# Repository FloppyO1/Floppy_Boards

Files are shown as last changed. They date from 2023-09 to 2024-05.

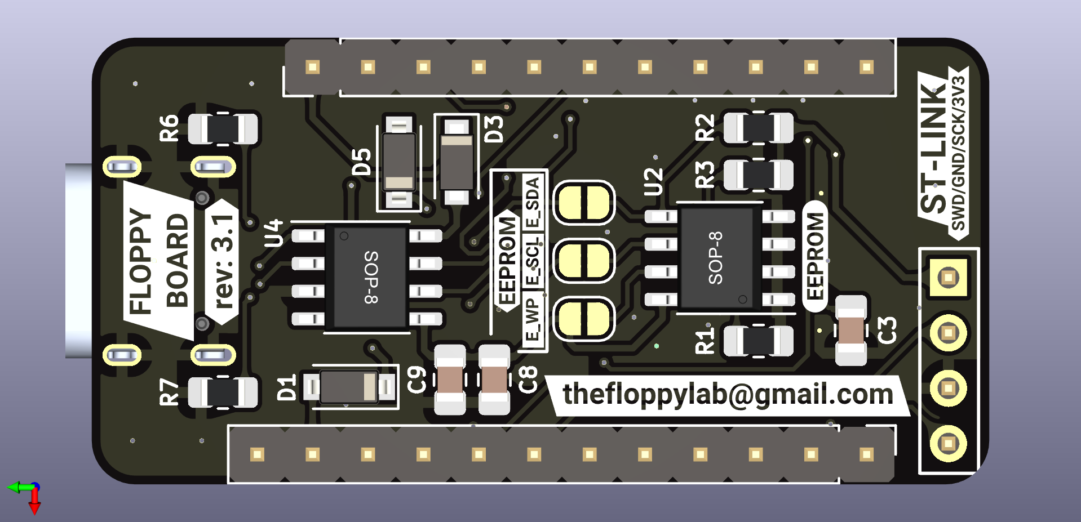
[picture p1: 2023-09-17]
Floppy Board/Floppy Board 3/Floppy Board v3.1/IMAGES/Floppy Board v3.1 bottom.png

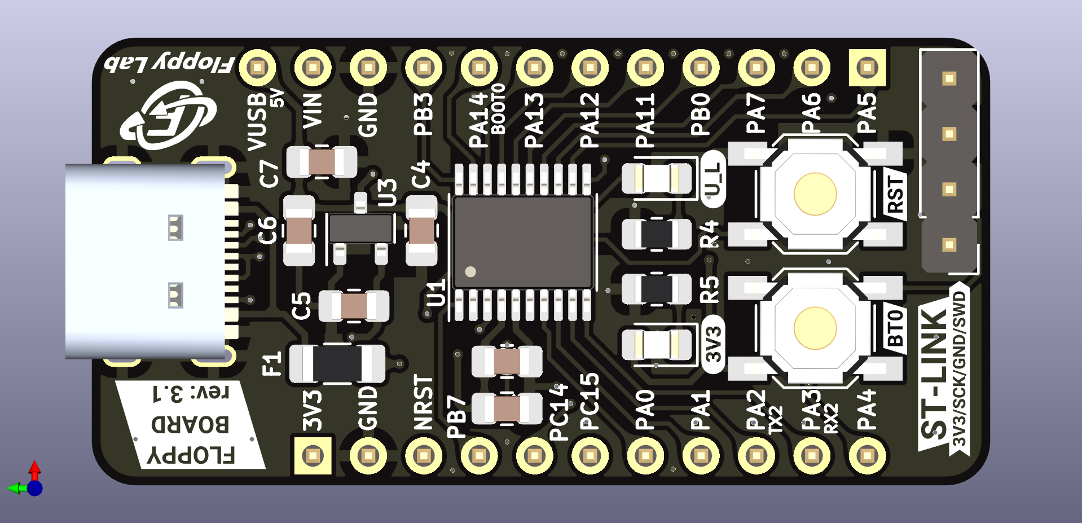
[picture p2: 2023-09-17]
Floppy Board/Floppy Board 3/Floppy Board v3.1/IMAGES/Floppy Board v3.1 top.png

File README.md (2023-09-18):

# Floppy_Boards
Floppy Boards are a series of breakout boards for rapid prototyping which I developed as an alternative of Arduino.

These boards can provide good performance and many useful modules (such as: USB, I2C, SPI, timers etc.). I want to make several models, in order to have different boards for different applications.
For example, I am considering developing options for:

- Built-in battery monitoring & charging.   (to be done)
- Built-in DC motor control.                (to be done)
- Built-in servos & stepper-motor control.  (to be done)

# Why as an alternative to Arduino boards?
I am building this board because I was looking for a cheap, powerful and well supported development board in the marketplace, but I don’t find anything I like. On the other hand, I am learning a lot while making these Floppy Boards.
## Features
- Programmable with Arduino IDE and STMCubeIDE
- Planty of the module
- Small dimensions
- Lots of GPIO

### The most recent version I've made
Floppy Bard 3.1

The third version of the Floppy Board, this board has incorporated all possible improvements regarding the interface between the Floppy Board and the computer.
In this version, it excels over the others in the following aspects:

- The last upgrade includes a USB-C port, allowing you to power our projects and load firmware directly without the need for an ST-Link.
- Additionally, the board has been further downsized, featuring two holes on each side when inserted into a breadboard!
- I've added a pin where you can access the incoming 5V voltage from the USB , enabling you to power external circuits directly from the convenient USB-C.
- The silkscreen has been completely updated, making it much more legible and aesthetically pleasing.
- inally, we've introduced the option to install an EEPROM on the back of the board , enabling you to permanently save small amounts of data even in the absence of power.

## Other informations

For more informations check my website: https://floppylab.altervista.org/en

You can also find some information on my YouTube channel: https://www.youtube.com/@floppylab

## Support this project with a donation

To support this project you can make a donation via PayPal or buy a Floppy Board:

https://www.paypal.com/paypalme/floppylab

https://ko-fi.com/floppylab



## License

[CERN Open Hardware Licence Version 2 - Strongly Reciprocal](https://choosealicense.com/licenses/cern-ohl-s-2.0/#)

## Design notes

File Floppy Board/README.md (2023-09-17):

# Floppy Board

Inside this folder there are all the files of the base version of the Floppy Board.

There are 3 major versions:
- v1.0, that is the first prototype that I've made.
- v2.0, which is the second attempt, is an improved version of 1.0, it is good because it is the smallest of the three versions.
- v3.x, which is the last version that includes the connections between the Floppy Board and the computer.



## License

[CERN Open Hardware Licence Version 2 - Strongly Reciprocal](https://choosealicense.com/licenses/cern-ohl-s-2.0/#)

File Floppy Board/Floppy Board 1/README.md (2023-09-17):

# Floppy Board rev:1.0

[](https://floppylab.altervista.org/wp-content/uploads/2023/09/FB-1-no-sfondo-960x768.png)

This is the first prototype of the Floppy Board.



## License

[CERN Open Hardware Licence Version 2 - Strongly Reciprocal](https://choosealicense.com/licenses/cern-ohl-s-2.0/#)

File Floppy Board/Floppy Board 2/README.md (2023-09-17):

# Floppy Board rev:2.0


This is the second version of the Floppy Board, and it includes a few small improvements that make it simpler and faster to use.
The improvements that I made are as follows:

- The total width has been reduced, allowing this version to be used with only one breadboard.
- The 3.3V output pin now has precisely 3.3V (3.263V), ensuring no more 3V output!
- Pin names have been added on each side of the board.
- The board now has a slimmer profile that makes it possible to use it upside down.
- The microcontroller is the same as the first Floppy Board, but it can be upgraded with an equivalent MCU that has double the FLASH memory. The more capable MCU is the STM32G031F8P6, which has 32kB more memory than the old one (so 64kB in total). These boards are compatible with Arduino IDE, meaning they can be easily programmed by users who are less experienced.



## License

[CERN Open Hardware Licence Version 2 - Strongly Reciprocal](https://choosealicense.com/licenses/cern-ohl-s-2.0/#)

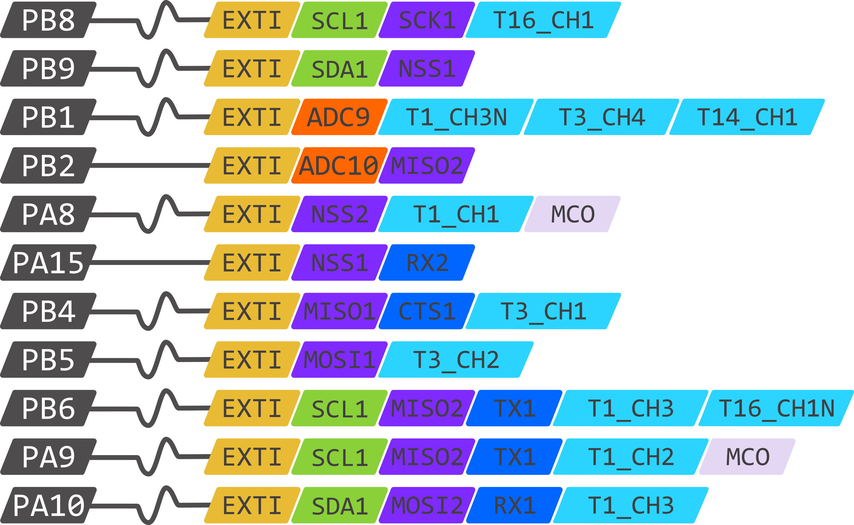
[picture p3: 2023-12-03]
pinouts/originals/fb3.1/pinout FB3 2.png

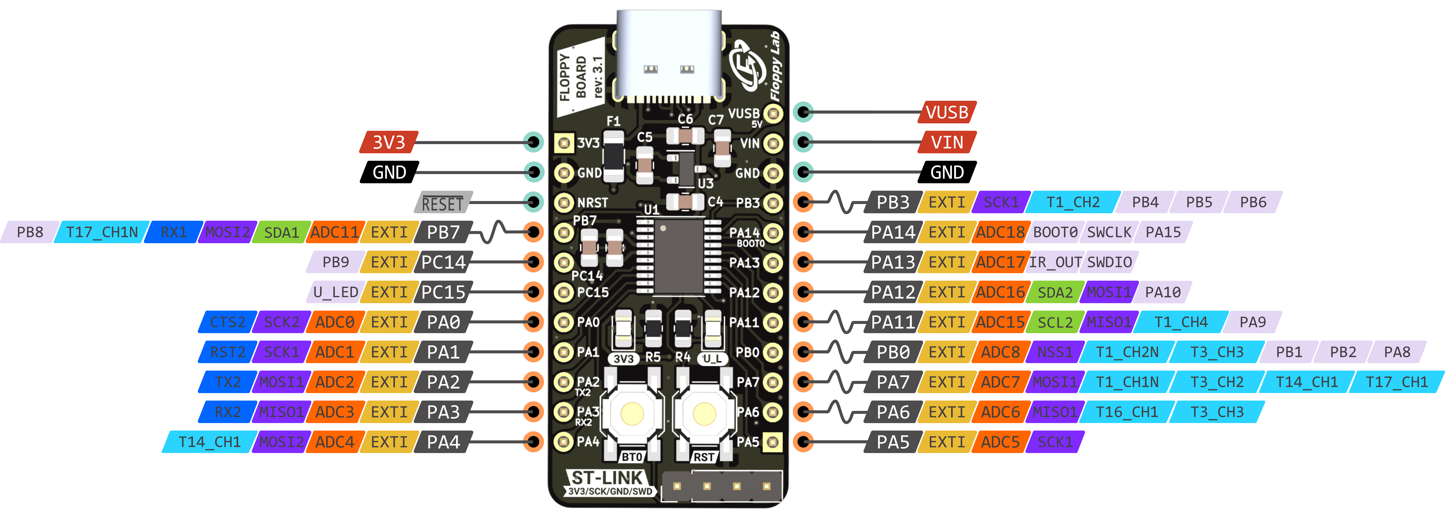
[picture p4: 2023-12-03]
pinouts/originals/fb3.1/pinout FB3 1.png

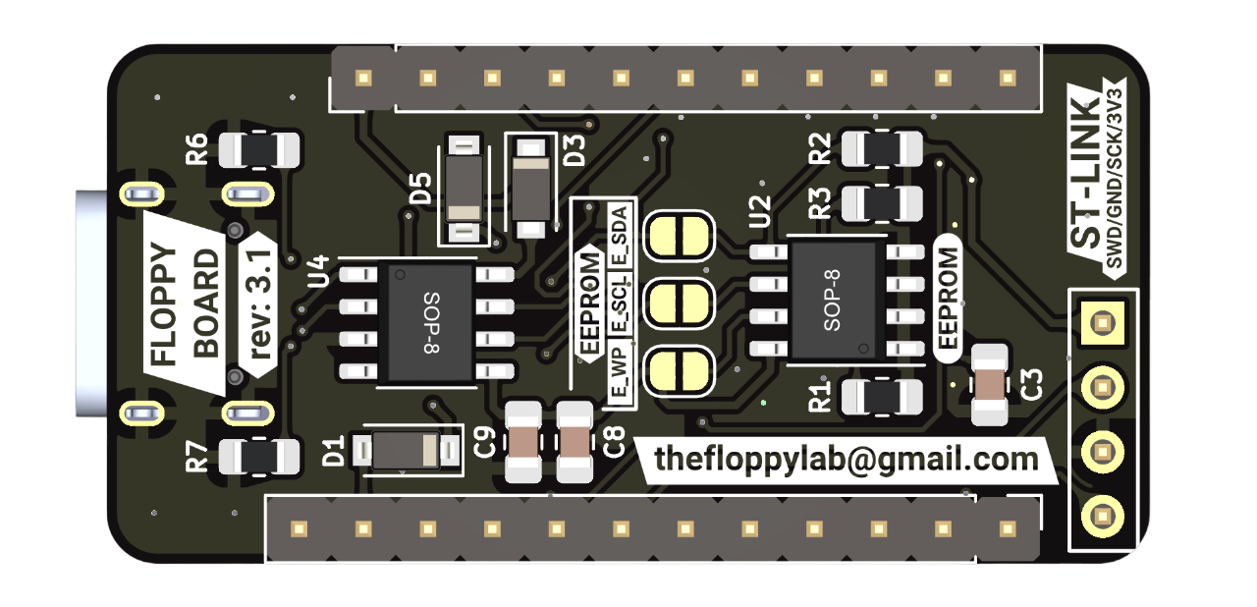
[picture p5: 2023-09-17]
Floppy Board/Floppy Board 3/Floppy Board v3.1/IMAGES/Floppy Board v3.1 bottom senza sfondo.png

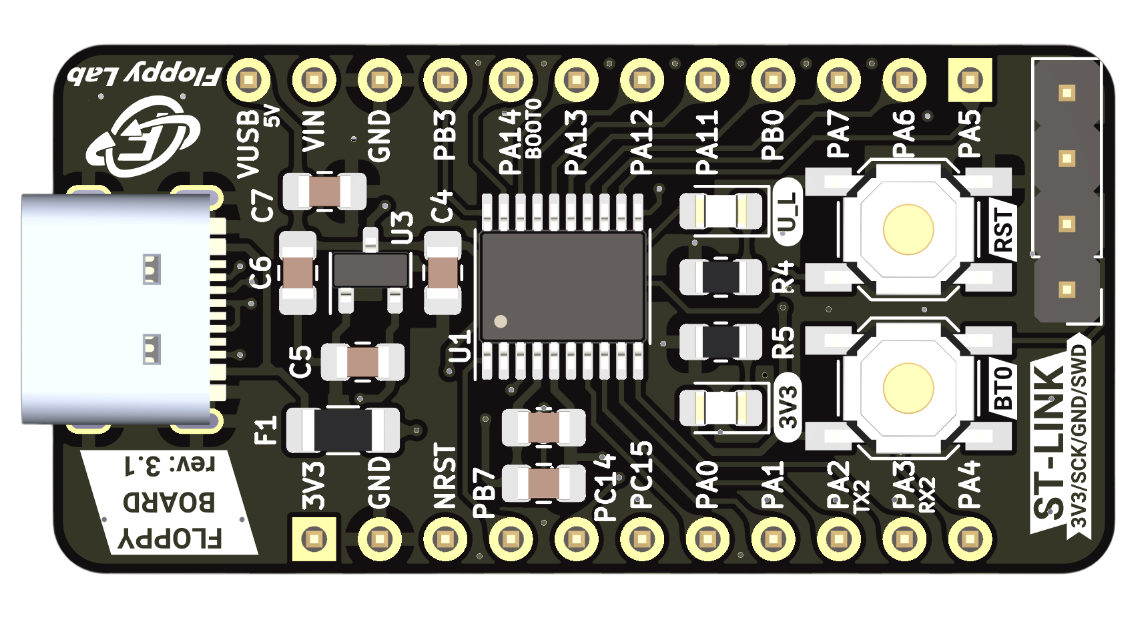
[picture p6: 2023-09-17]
Floppy Board/Floppy Board 3/Floppy Board v3.1/IMAGES/Floppy Board v3.1 top senza sfondo.png

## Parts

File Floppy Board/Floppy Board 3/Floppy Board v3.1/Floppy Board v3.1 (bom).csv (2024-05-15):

Reference | Value | Footprint | Qtà
C1 | 4.7uF | Capacitor_SMD:C_0805_2012Metric_Pad1.18x1.45mm_HandSolder | 1
C2, C3, C6, C8, C9 | 100nF | Capacitor_SMD:C_0805_2012Metric_Pad1.18x1.45mm_HandSolder | 5
C4, C5 | 1uF | Capacitor_SMD:C_0805_2012Metric_Pad1.18x1.45mm_HandSolder | 2
C7 | 10uF | Capacitor_SMD:C_0805_2012Metric_Pad1.18x1.45mm_HandSolder | 1
D1, D5 | SD103AW | Diode_SMD:D_SOD-123 | 2
D2 | USER_LED | LED_SMD:LED_0805_2012Metric_Pad1.15x1.40mm_HandSolder | 1
D3 | SD103AW | Diode_SMD:D_SOD-123F | 1
D4 | 3V3_POWER_LED | LED_SMD:LED_0805_2012Metric_Pad1.15x1.40mm_HandSolder | 1
F1 | 500mA | Fuse:Fuse_1206_3216Metric_Pad1.42x1.75mm_HandSolder | 1
J1 | st-link | Connector_PinHeader_2.54mm:PinHeader_1x04_P2.54mm_Vertical | 1
J2 | USB-C_304A-ACP16X | _MIA footprint:USB_C_304A-ACP16X | 1
J3 | I/O SX | Connector_PinHeader_2.54mm:PinHeader_1x11_P2.54mm_Vertical | 1
J4 | I/0 DX | Connector_PinHeader_2.54mm:PinHeader_1x12_P2.54mm_Vertical | 1
JP1 | SDA_JP | Jumper:SolderJumper-2_P1.3mm_Open_RoundedPad1.0x1.5mm | 1
JP2 | SCL_JP | Jumper:SolderJumper-2_P1.3mm_Open_RoundedPad1.0x1.5mm | 1
JP3 | WP_JP | Jumper:SolderJumper-2_P1.3mm_Open_RoundedPad1.0x1.5mm | 1
R1 | 10k | Resistor_SMD:R_0805_2012Metric_Pad1.20x1.40mm_HandSolder | 1
R2, R3, R6, R7 | 5.1k | Resistor_SMD:R_0805_2012Metric_Pad1.20x1.40mm_HandSolder | 4
R4 | 1K | Resistor_SMD:R_0805_2012Metric_Pad1.20x1.40mm_HandSolder | 1
R5 | 1k | Resistor_SMD:R_0805_2012Metric_Pad1.20x1.40mm_HandSolder | 1
SW1 | RESET_B | _MIA footprint:SMD BUTTON 5.1x5.1 | 1
SW2 | BOOT0/U_BUTT | _MIA footprint:SMD BUTTON 5.1x5.1 | 1
U1 | STM32G03xxxxx | Package_SO:TSSOP-20_4.4x6.5mm_P0.65mm | 1
U2 | AT24C32 | Package_SO:SOP-8_3.9x4.9mm_P1.27mm | 1
U3 | H7233-1 | Package_TO_SOT_SMD:SOT-23 | 1
U4 | CH340N | Package_SO:SOP-8_3.9x4.9mm_P1.27mm | 1

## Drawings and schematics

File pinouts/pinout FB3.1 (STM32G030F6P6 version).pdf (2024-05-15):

## STM32G030F6P6 version

# Floppy Board 3.1 PINOUT

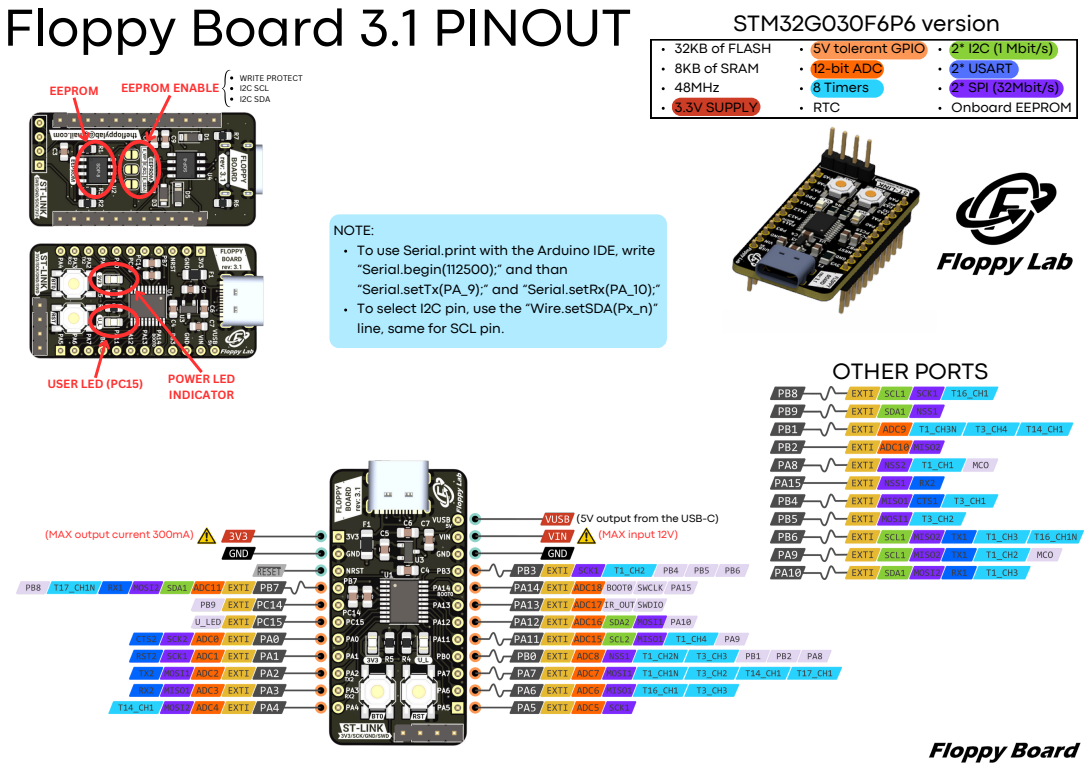
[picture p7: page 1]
3.3V SUPPLY; RTC; Onboard EEPROM; OTHER PORTS; (MAX output current 300mA); (MAX input 12V); EEPROM; EEPROM ENABLE; WRITE PROTECT I2C SCL I2C SDA; POWER LED INDICATOR; USER LED (PC15)

32KB of FLASH 8KB of SRAM 48MHz | 5V tolerant GPIO | | 2* I2C (1 Mbit/s)

12-bit ADC | | 2* USART
8 Timers | | 2* SPI (32Mbit/s)

NOTE:
To use Serial.print with the Arduino IDE, write
“Serial.begin(112500);” and than
“Serial.setTx(PA_9);” and “Serial.setRx(PA_10);”
To select I2C pin, use the “Wire.setSDA(Px_n)”
line, same for SCL pin.

(5V output from the USB-C)

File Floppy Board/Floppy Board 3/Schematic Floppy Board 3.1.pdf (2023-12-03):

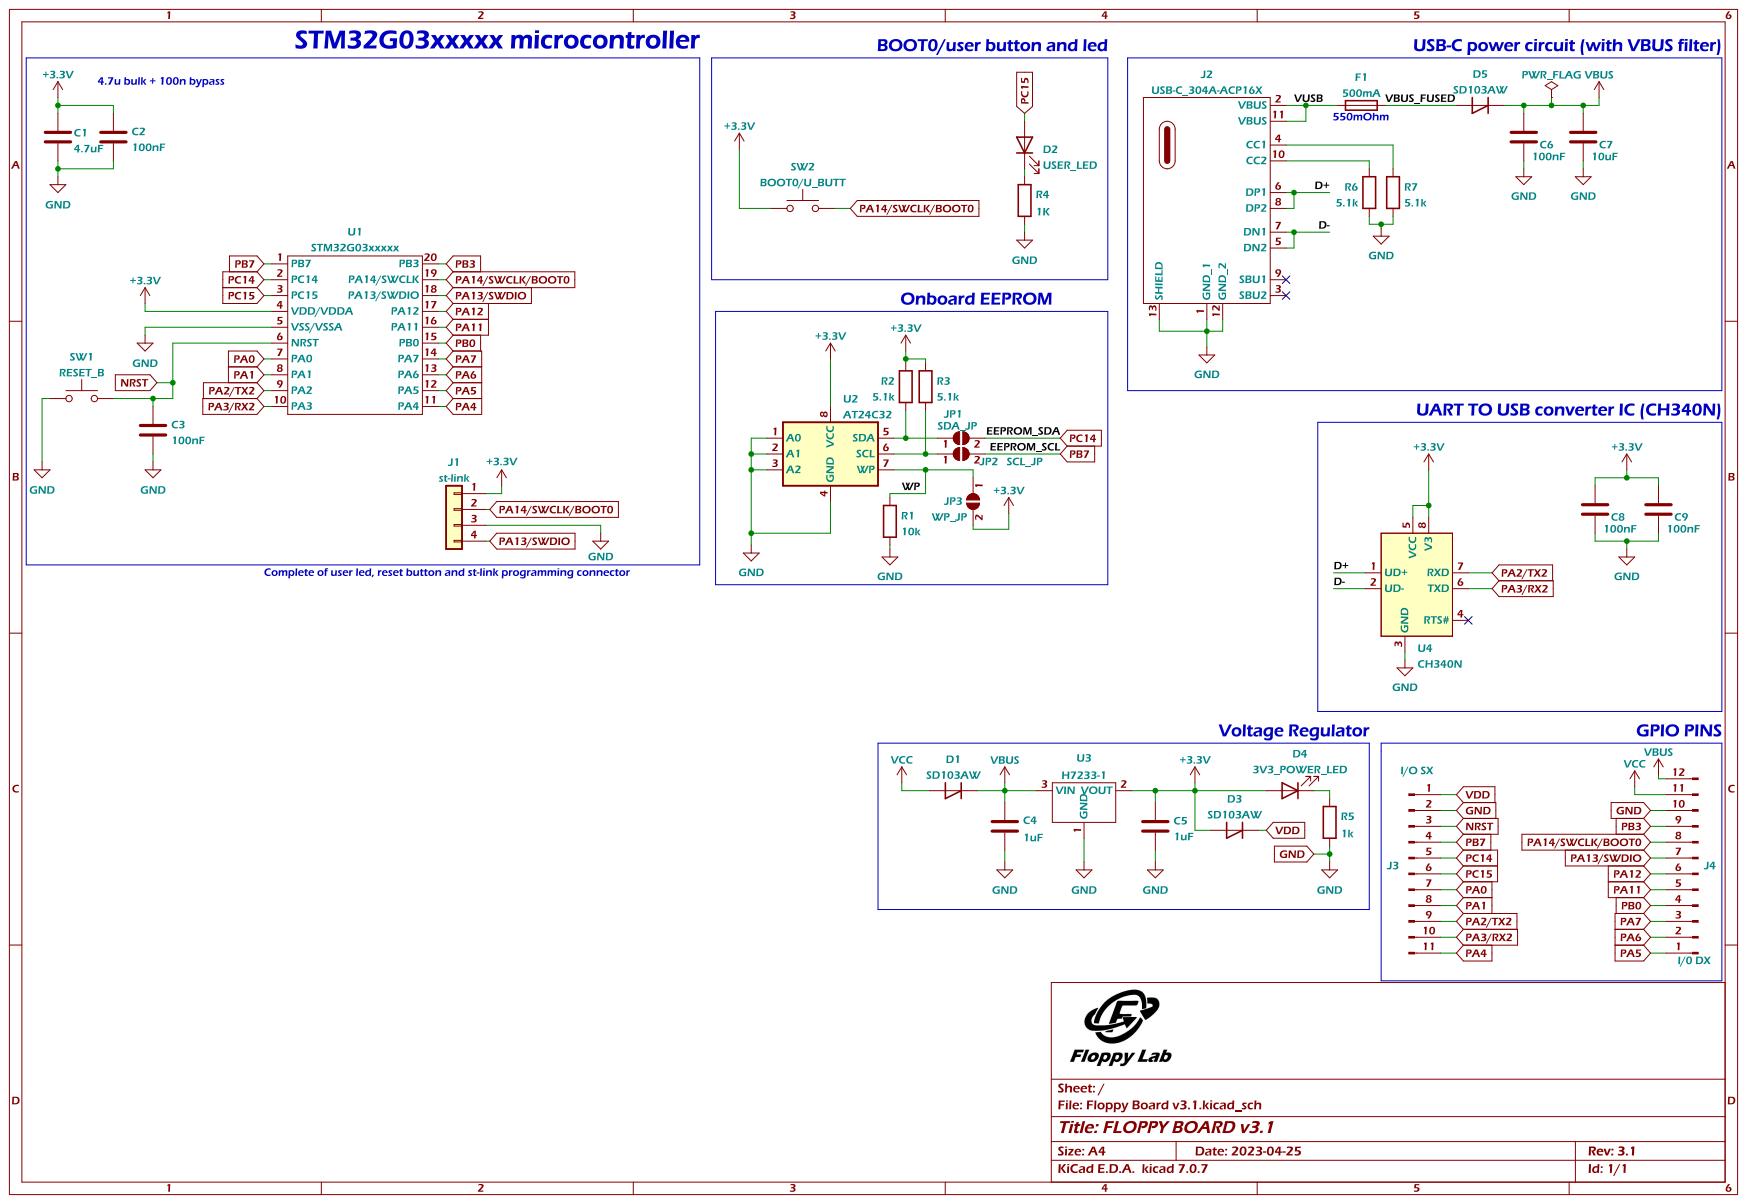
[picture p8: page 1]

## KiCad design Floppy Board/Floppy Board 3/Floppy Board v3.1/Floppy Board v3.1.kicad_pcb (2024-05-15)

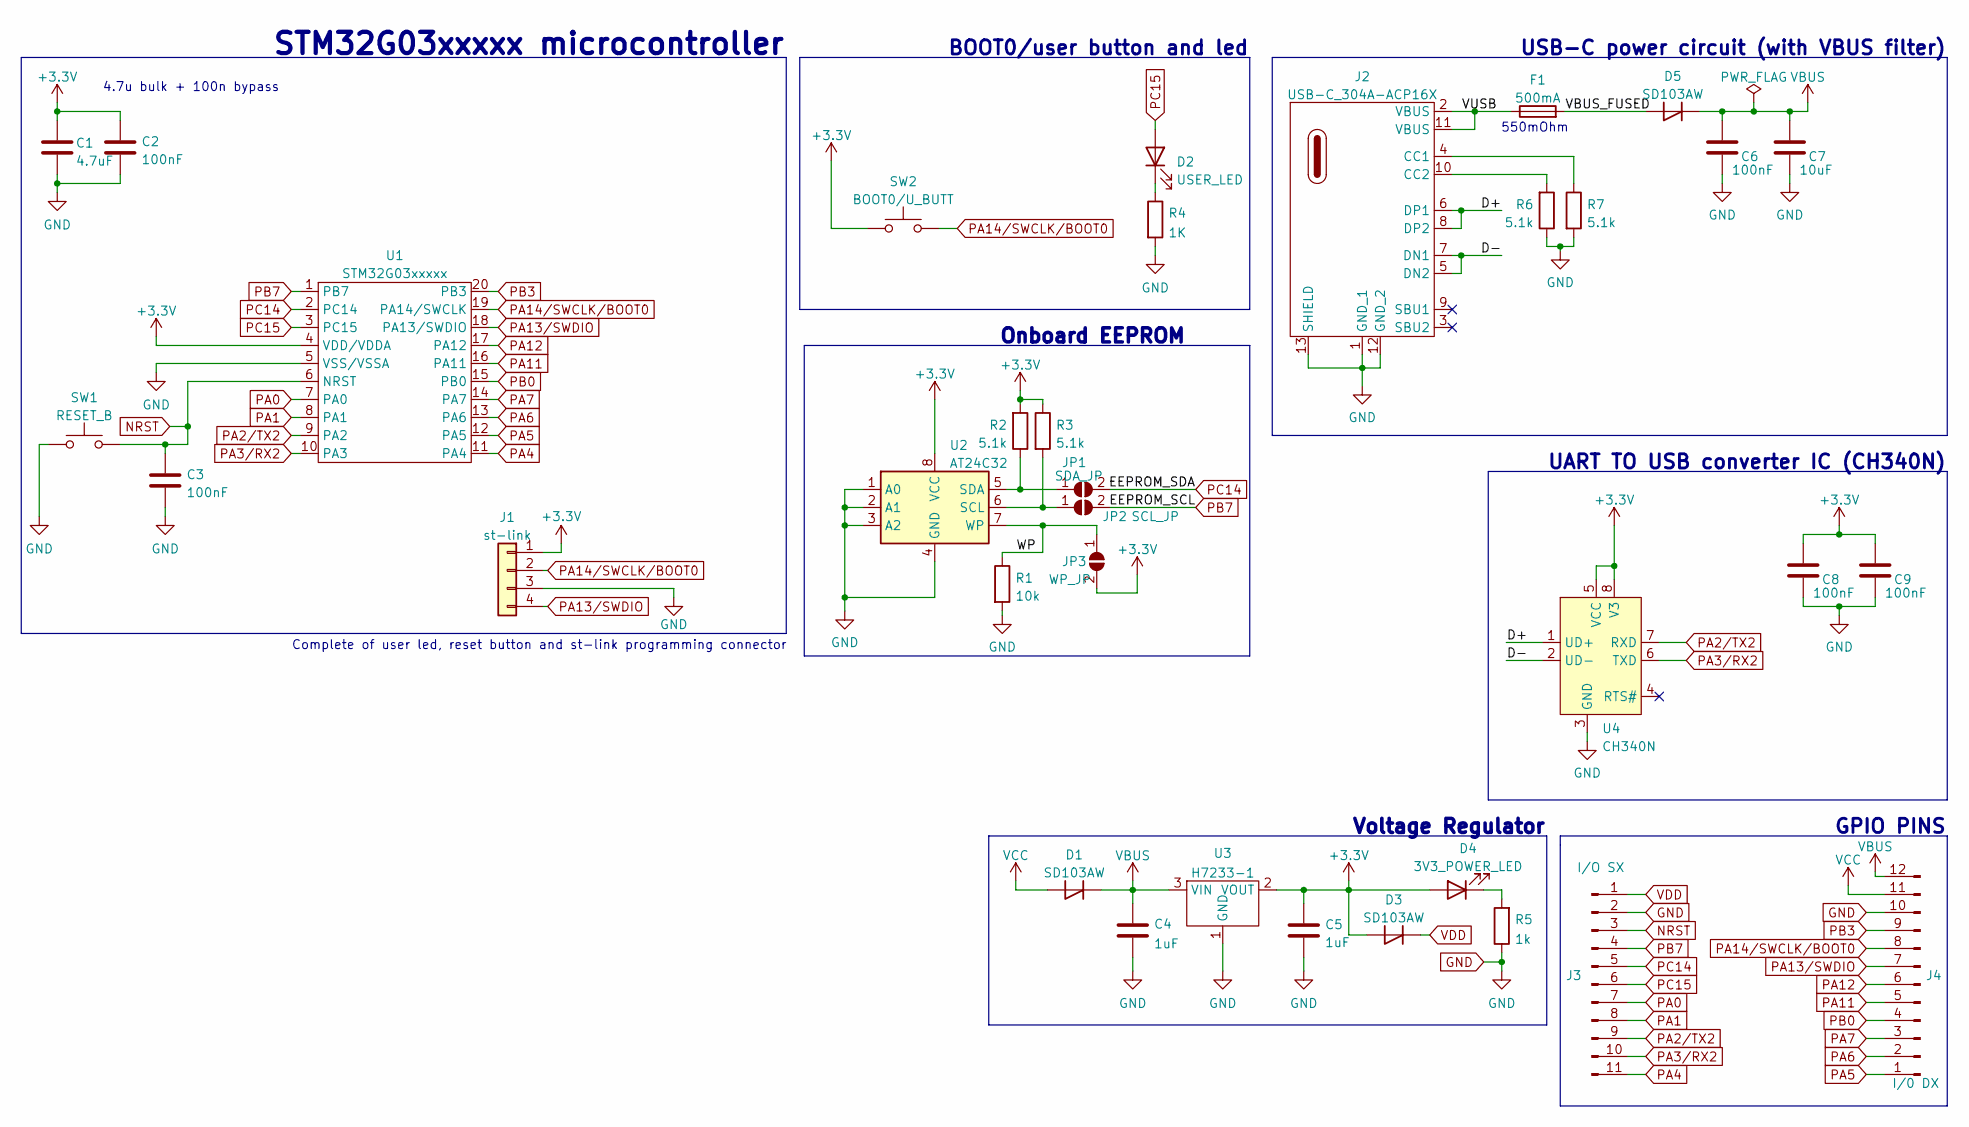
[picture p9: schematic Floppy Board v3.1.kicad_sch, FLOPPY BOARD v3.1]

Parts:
C1: 4.7uF; C_0805_2012Metric_Pad1.18x1.45mm_HandSolder
C2, C3, C6, C8, C9: 100nF; C_0805_2012Metric_Pad1.18x1.45mm_HandSolder
C4, C5: 1uF; C_0805_2012Metric_Pad1.18x1.45mm_HandSolder
C7: 10uF; C_0805_2012Metric_Pad1.18x1.45mm_HandSolder
D1, D5: SD103AW; D_SOD-123
D2: USER_LED; LED_0805_2012Metric_Pad1.15x1.40mm_HandSolder
D3: SD103AW; D_SOD-123F
D4: 3V3_POWER_LED; LED_0805_2012Metric_Pad1.15x1.40mm_HandSolder
F1: 500mA; Fuse_1206_3216Metric_Pad1.42x1.75mm_HandSolder
J1: st-link; PinHeader_1x04_P2.54mm_Vertical
J2: USB-C_304A-ACP16X; USB_C_304A-ACP16X
J3: I/O SX; PinHeader_1x11_P2.54mm_Vertical
J4: I/0 DX; PinHeader_1x12_P2.54mm_Vertical
JP1: SDA_JP; SolderJumper-2_P1.3mm_Open_RoundedPad1.0x1.5mm
JP2: SCL_JP; SolderJumper-2_P1.3mm_Open_RoundedPad1.0x1.5mm
JP3: WP_JP; SolderJumper-2_P1.3mm_Open_RoundedPad1.0x1.5mm
R1: 10k; R_0805_2012Metric_Pad1.20x1.40mm_HandSolder
R2, R3, R6, R7: 5.1k; R_0805_2012Metric_Pad1.20x1.40mm_HandSolder
R4: 1K; R_0805_2012Metric_Pad1.20x1.40mm_HandSolder
R5: 1k; R_0805_2012Metric_Pad1.20x1.40mm_HandSolder
SW1: RESET_B; SMD BUTTON 5.1x5.1
SW2: BOOT0/U_BUTT; SMD BUTTON 5.1x5.1
U1: STM32G03xxxxx; TSSOP-20_4.4x6.5mm_P0.65mm
U2: AT24C32; SOP-8_3.9x4.9mm_P1.27mm
U3: H7233-1; SOT-23
U4: CH340N; SOP-8_3.9x4.9mm_P1.27mm

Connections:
+3V3: C1.1, C2.1, C5.1, C8.1, C9.1, D3.2 (A), D4.2 (A), J1.1, JP3.2 (B), R2.2, R3.1, SW2.1, U1.4 (VDD/VDDA), U2.8 (VCC), U3.2 (VOUT), U4.5 (VCC), U4.8 (V3)
/D+: J2.6 (DP1), J2.8 (DP2), U4.1 (UD+)
/D-: J2.5 (DN2), J2.7 (DN1), U4.2 (UD-)
/VBUS_FUSED: D5.2 (A), F1.2
/VUSB: F1.1, J2.2 (VBUS), J2.11 (VBUS)
/WP: JP3.1 (A), R1.1, U2.7 (WP)
GND: C1.2, C2.2, C3.2, C4.2, C5.2, C6.2, C7.2, C8.2, C9.2, J1.3, J2.1 (GND_1), J2.12 (GND_2), J2.13 (SHIELD), J3.2, J4.10, R1.2, R4.2, R5.1, R6.1, R7.2, SW1.1, U1.5 (VSS/VSSA), U2.1 (A0), U2.2 (A1), U2.3 (A2), U2.4 (GND), U3.1 (GND), U4.3 (GND)
NRST: C3.1, J3.3, SW1.2, U1.6 (NRST)
unnamed: D2.1 (K), R4.1
unnamed: D4.1 (K), R5.2
unnamed: J2.4 (CC1), R7.1
unnamed: J2.10 (CC2), R6.2
unnamed: JP1.1 (A), R2.1, U2.5 (SDA)
unnamed: JP2.1 (A), R3.2, U2.6 (SCL)
PA0: J3.7, U1.7 (PA0)
PA1: J3.8, U1.8 (PA1)
PA2/TX2: J3.9, U1.9 (PA2), U4.7 (RXD)
PA3/RX2: J3.10, U1.10 (PA3), U4.6 (TXD)
PA4: J3.11, U1.11 (PA4)
PA5: J4.1, U1.12 (PA5)
PA6: J4.2, U1.13 (PA6)
PA7: J4.3, U1.14 (PA7)
PA11: J4.5, U1.16 (PA11)
PA12: J4.6, U1.17 (PA12)
PA13/SWDIO: J1.4, J4.7, U1.18 (PA13/SWDIO)
PA14/SWCLK/BOOT0: J1.2, J4.8, SW2.2, U1.19 (PA14/SWCLK)
PB0: J4.4, U1.15 (PB0)
PB3: J4.9, U1.20 (PB3)
PB7: J3.4, JP2.2 (B), U1.1 (PB7)
PC14: J3.5, JP1.2 (B), U1.2 (PC14)
PC15: D2.2 (A), J3.6, U1.3 (PC15)
VBUS: C4.1, C6.1, C7.1, D1.1 (K), D5.1 (K), J4.12, U3.3 (VIN)
VCC: D1.2 (A), J4.11
VDD: D3.1 (K), J3.1

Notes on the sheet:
USB-C power circuit (with VBUS filter)
4.7u bulk + 100n bypass
Voltage Regulator
STM32G03xxxxx microcontroller
550mOhm
GPIO PINS
UART TO USB converter IC (CH340N)
BOOT0/user button and led
Complete of user led, reset button and st-link programming connector
Onboard EEPROM

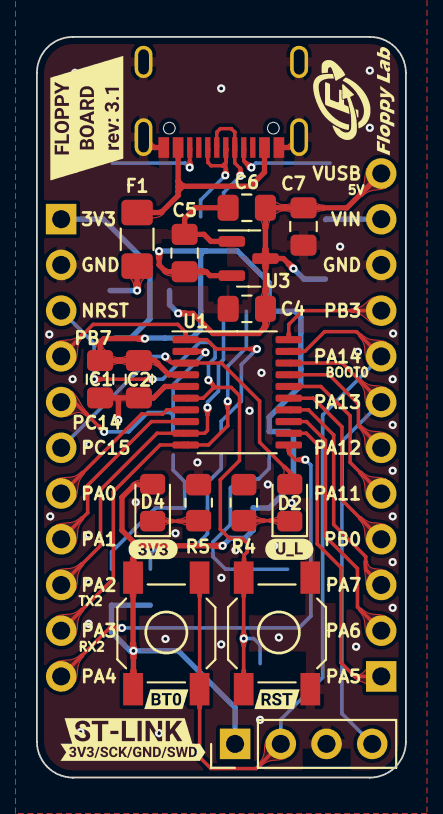
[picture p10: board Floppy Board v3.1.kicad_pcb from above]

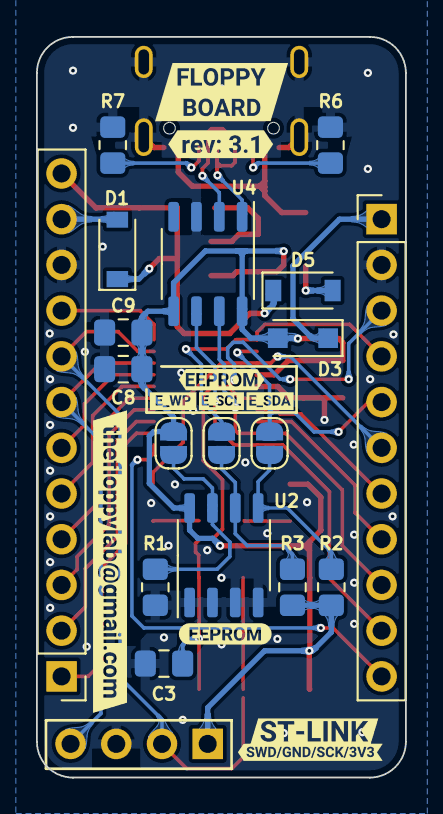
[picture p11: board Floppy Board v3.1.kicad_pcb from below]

Board: 2 copper layers, 20.5 x 41.1 mm, 52 parts (28 on the bottom side), 34 nets.

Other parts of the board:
kibuzzard-644D5A83: G***; kibuzzard-644D5A83
kibuzzard-644D5AD1: G***; kibuzzard-644D5AD1
kibuzzard-644D5AFD: G***; kibuzzard-644D5AFD
kibuzzard-644D5B14: G***; kibuzzard-644D5B14
kibuzzard-644D5C5F: G***; kibuzzard-644D5C5F
kibuzzard-644D5C68: G***; kibuzzard-644D5C68
kibuzzard-644D5C93: G***; kibuzzard-644D5C93
kibuzzard-644D5CBA: G***; kibuzzard-644D5CBA
kibuzzard-644D5F43: G***; kibuzzard-644D5F43
kibuzzard-644D56F9: G***; kibuzzard-644D56F9
kibuzzard-644D58F1: G***; kibuzzard-644D58F1
kibuzzard-644D571B: G***; kibuzzard-644D571B
kibuzzard-644D5750: G***; kibuzzard-644D5750
kibuzzard-644D5758: G***; kibuzzard-644D5758
kibuzzard-644D5814: G***; kibuzzard-644D5814
kibuzzard-644D5953: G***; kibuzzard-644D5953
kibuzzard-644D6722: G***; kibuzzard-644D6722

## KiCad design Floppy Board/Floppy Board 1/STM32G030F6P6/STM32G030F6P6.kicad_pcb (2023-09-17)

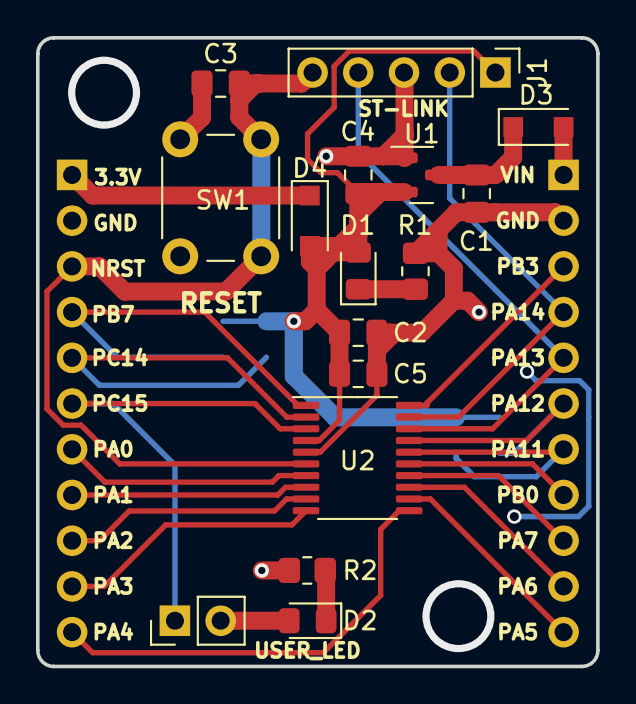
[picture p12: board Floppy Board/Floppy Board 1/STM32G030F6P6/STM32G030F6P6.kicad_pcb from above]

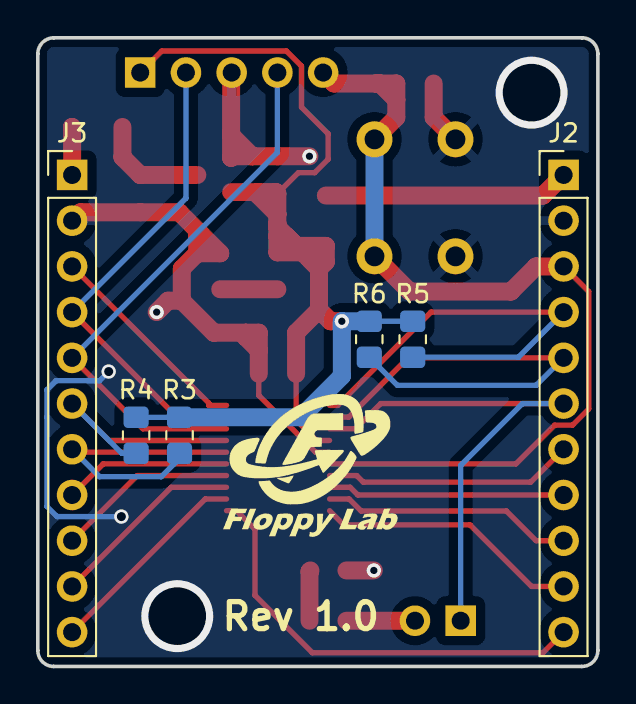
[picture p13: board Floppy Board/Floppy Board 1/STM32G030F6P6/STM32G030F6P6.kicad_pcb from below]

Board: 2 copper layers, 31.1 x 34.9 mm, 22 parts (6 on the bottom side), 26 nets.

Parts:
C1, C4: 1u; C_0805_2012Metric_Pad1.18x1.45mm_HandSolder
C2: 4.7u; C_0805_2012Metric_Pad1.18x1.45mm_HandSolder
C3: 0.1U; C_0805_2012Metric_Pad1.18x1.45mm_HandSolder
C5: 100n; C_0805_2012Metric_Pad1.18x1.45mm_HandSolder
D1: POWER_LED; LED_0805_2012Metric_Pad1.15x1.40mm_HandSolder
D2: USER_LED; LED_0805_2012Metric_Pad1.15x1.40mm_HandSolder
D3, D4: 1N4002; D_SOD-123F
J1: stlink; PinHeader_1x05_P2.54mm_Vertical
J2: I/O SX; PinHeader_1x11_P2.54mm_Vertical
J3: I/0 DX; PinHeader_1x11_P2.54mm_Vertical
JP1: UL JUMP.; PinHeader_1x02_P2.54mm_Vertical
R1: 1k; R_0805_2012Metric_Pad1.20x1.40mm_HandSolder
R2: 1K; R_0805_2012Metric_Pad1.20x1.40mm_HandSolder
R3, R4, R5, R6: 4.7k; R_0805_2012Metric_Pad1.20x1.40mm_HandSolder
SW1: RESET_BUTTON; SW_PUSH_6mm
U1: H7233-1; SOT-23
U2: STM32G030F6P6; TSSOP-20_4.4x6.5mm_P0.65mm

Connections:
+3V3: C2.1, C4.1, C5.1, D1.2 (A), D4.2 (A), J1.1, R3.1, R4.1, R5.1, R6.1, U1.2 (VOUT), U2.4 (VDD/VDDA)
GND: C1.2, C2.2, C3.2, C4.2, C5.2, J1.3, J2.2, J3.2, R1.1, R2.2, SW1.1, U1.1 (GND), U2.5 (VSS/VSSA)
NRST: C3.1, J1.5, J2.3, SW1.2, U2.6 (NRST)
unnamed: C1.1, D3.1 (K), U1.3 (VIN)
unnamed: D1.1 (K), R1.2
unnamed: D2.1 (K), R2.1
unnamed: D2.2 (A), JP1.2 (B)
PA0: J2.7, U2.7 (PA0)
PA1: J2.8, U2.8 (PA1)
PA2: J2.9, U2.9 (PA2)
PA3: J2.10, U2.10 (PA3)
PA4: J2.11, U2.11 (PA4)
PA5: J3.11, U2.12 (PA5)
PA6: J3.10, U2.13 (PA6)
PA7: J3.9, U2.14 (PA7)
PA11: J3.7, R3.2, U2.16 (PA11)
PA12: J3.6, R4.2, U2.17 (PA12)
PA13/SWDIO: J1.4, J3.5, U2.18 (PA13/SWDIO)
PA14/SWCLK: J1.2, J3.4, U2.19 (PA14/SWCLK)
PB0: J3.8, U2.15 (PB0)
PB3: J3.3, U2.20 (PB3)
PB7: J2.4, R5.2, U2.1 (PB7)
PC14: J2.5, R6.2, U2.2 (PC14)
PC15: J2.6, JP1.1 (A), U2.3 (PC15)
VDD: D4.1 (K), J2.1
VIN: D3.2 (A), J3.1

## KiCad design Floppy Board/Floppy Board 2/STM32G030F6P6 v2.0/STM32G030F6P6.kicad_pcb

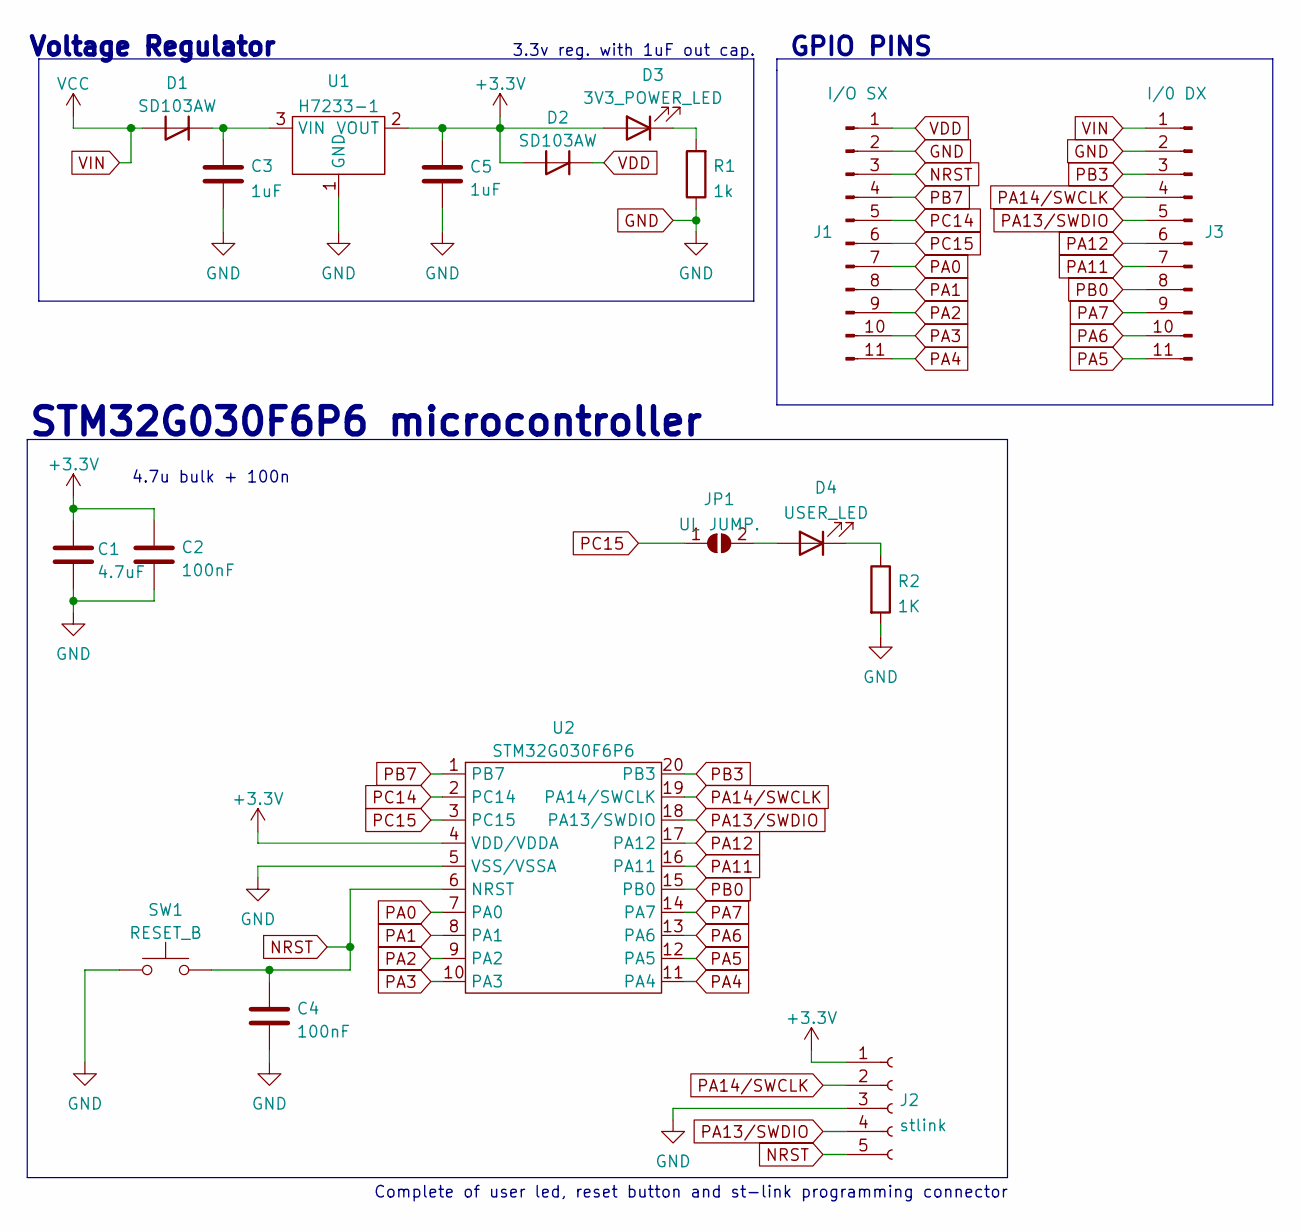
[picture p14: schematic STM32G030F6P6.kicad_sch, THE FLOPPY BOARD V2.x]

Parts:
C1: 4.7uF; C_0805_2012Metric_Pad1.18x1.45mm_HandSolder
C2, C4: 100nF; C_0805_2012Metric_Pad1.18x1.45mm_HandSolder
C3, C5: 1uF; C_0805_2012Metric_Pad1.18x1.45mm_HandSolder
D1: SD103AW; D_SOD-123
D2: SD103AW; D_SOD-123F
D3: 3V3_POWER_LED; LED_0805_2012Metric_Pad1.15x1.40mm_HandSolder
D4: USER_LED; LED_0805_2012Metric_Pad1.15x1.40mm_HandSolder
J1: I/O SX; PinHeader_1x11_P2.54mm_Vertical
J2: stlink; PinHeader_1x05_P2.54mm_Vertical
J3: I/0 DX; PinHeader_1x11_P2.54mm_Vertical
JP1: UL JUMP.; SolderJumper-2_P1.3mm_Open_RoundedPad1.0x1.5mm
R1: 1k; R_0805_2012Metric_Pad1.20x1.40mm_HandSolder
R2: 1K; R_0805_2012Metric_Pad1.20x1.40mm_HandSolder
SW1: RESET_B; SMD BUTTON 5.1x5.1
U1: H7233-1; SOT-23
U2: STM32G030F6P6; TSSOP-20_4.4x6.5mm_P0.65mm

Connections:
+3V3: C1.1, C2.1, C5.1, D2.2 (A), D3.2 (A), J2.1, U1.2 (VOUT), U2.4 (VDD/VDDA)
GND: C1.2, C2.2, C3.2, C4.2, C5.2, J1.2, J2.3, J3.2, R1.1, R2.2, SW1.1, U1.1 (GND), U2.5 (VSS/VSSA)
NRST: C4.1, J1.3, J2.5, SW1.2, U2.6 (NRST)
unnamed: C3.1, D1.1 (K), U1.3 (VIN)
unnamed: D3.1 (K), R1.2
unnamed: D4.1 (K), R2.1
unnamed: D4.2 (A), JP1.2 (B)
PA0: J1.7, U2.7 (PA0)
PA1: J1.8, U2.8 (PA1)
PA2: J1.9, U2.9 (PA2)
PA3: J1.10, U2.10 (PA3)
PA4: J1.11, U2.11 (PA4)
PA5: J3.11, U2.12 (PA5)
PA6: J3.10, U2.13 (PA6)
PA7: J3.9, U2.14 (PA7)
PA11: J3.7, U2.16 (PA11)
PA12: J3.6, U2.17 (PA12)
PA13/SWDIO: J2.4, J3.5, U2.18 (PA13/SWDIO)
PA14/SWCLK: J2.2, J3.4, U2.19 (PA14/SWCLK)
PB0: J3.8, U2.15 (PB0)
PB3: J3.3, U2.20 (PB3)
PB7: J1.4, U2.1 (PB7)
PC14: J1.5, U2.2 (PC14)
PC15: J1.6, JP1.1 (A), U2.3 (PC15)
VDD: D2.1 (K), J1.1
VIN: D1.2 (A), J3.1

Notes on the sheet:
3.3v reg. with 1uF out cap.
GPIO PINS
4.7u bulk + 100n
Complete of user led, reset button and st-link programming connector
STM32G030F6P6 microcontroller
Voltage Regulator

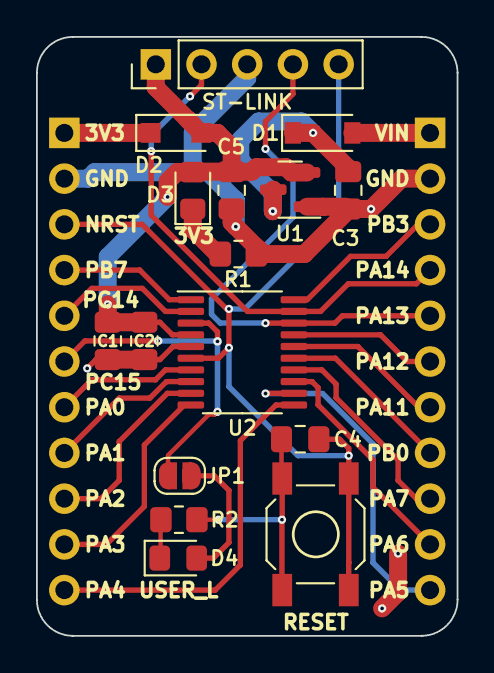
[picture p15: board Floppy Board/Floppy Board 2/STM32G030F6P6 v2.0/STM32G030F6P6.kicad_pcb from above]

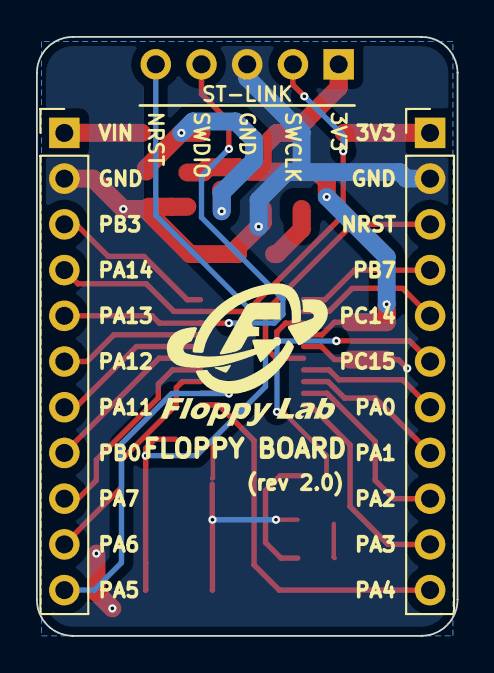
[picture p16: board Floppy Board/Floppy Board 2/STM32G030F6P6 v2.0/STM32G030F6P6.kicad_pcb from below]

Board: 2 copper layers, 23.4 x 33.3 mm, 18 parts (2 on the bottom side), 26 nets.

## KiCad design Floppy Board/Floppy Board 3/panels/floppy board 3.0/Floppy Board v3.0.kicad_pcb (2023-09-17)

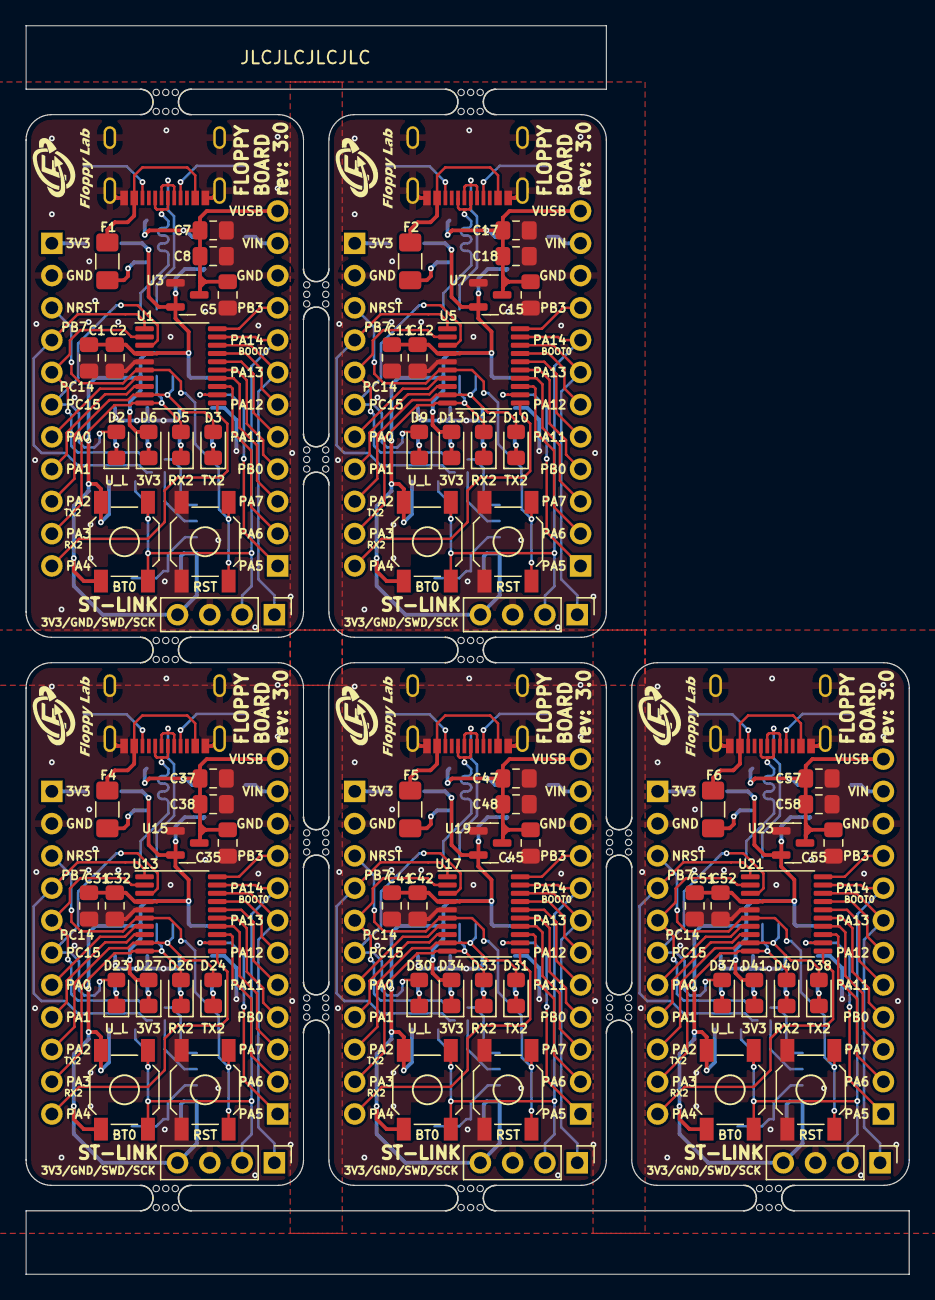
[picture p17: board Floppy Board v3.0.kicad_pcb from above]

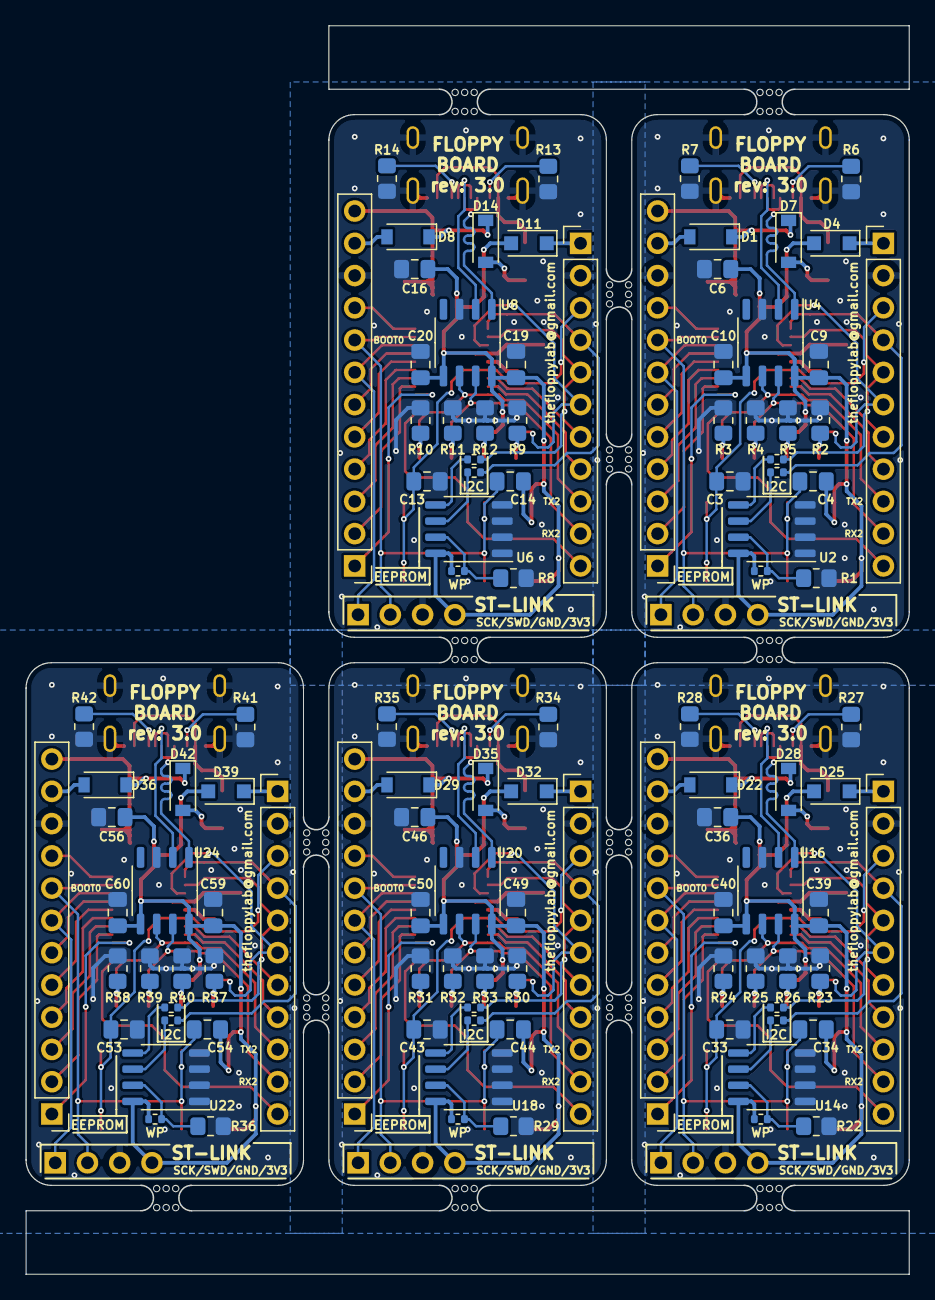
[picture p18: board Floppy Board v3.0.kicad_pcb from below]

Board: 2 copper layers, 69.5 x 98.3 mm, 203 parts (110 on the bottom side), 36 nets.

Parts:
C1, C11, C31, C41, C51: 4.7uF; C_0805_2012Metric_Pad1.18x1.45mm_HandSolder
C2, C3, C4, C7, C9, C10, C12, C13, C14, C17, C19, C20, C32, C33, C34, C37, C39, C40, C42, C43, C44, C47, C49, C50, C52, C53, C54, C57, C59, C60: 100nF; C_0805_2012Metric_Pad1.18x1.45mm_HandSolder
C5, C6, C15, C16, C35, C36, C45, C46, C55, C56: 1uF; C_0805_2012Metric_Pad1.18x1.45mm_HandSolder
C8, C18, C38, C48, C58: 10uF; C_0805_2012Metric_Pad1.18x1.45mm_HandSolder
D1, D7, D8, D14, D22, D28, D29, D35, D36, D42: SD103AW; D_SOD-123
D2, D9, D23, D30, D37: USER_LED; LED_0805_2012Metric_Pad1.15x1.40mm_HandSolder
D3, D10, D24, D31, D38: TX2; LED_0805_2012Metric_Pad1.15x1.40mm_HandSolder
D4, D11, D25, D32, D39: SD103AW; D_SOD-123F
D5, D12, D26, D33, D40: RX2; LED_0805_2012Metric_Pad1.15x1.40mm_HandSolder
D6, D13, D27, D34, D41: 3V3_POWER_LED; LED_0805_2012Metric_Pad1.15x1.40mm_HandSolder
F1, F2, F4, F5, F6: 500mA; Fuse_1206_3216Metric_Pad1.42x1.75mm_HandSolder
J1, J5, J13, J17, J21: st-link; PinHeader_1x04_P2.54mm_Vertical
J2, J6, J14, J18, J22: USB-C_304A-ACP16X; USB_C_304A-ACP16X
J3, J7, J15, J19, J23: I/O SX; PinHeader_1x11_P2.54mm_Vertical
J4, J8, J16, J20, J24: I/0 DX; PinHeader_1x12_P2.54mm_Vertical
JP1, JP4, JP10, JP13, JP16: SDA_JP; R_0402_1005Metric
JP2, JP5, JP11, JP14, JP17: SCL_JP; R_0402_1005Metric
JP3, JP6, JP12, JP15, JP18: WP_JP; R_0402_1005Metric
R1, R8, R22, R29, R36: 10k; R_0805_2012Metric_Pad1.20x1.40mm_HandSolder
R2, R3, R4, R9, R10, R11, R23, R24, R25, R30, R31, R32, R37, R38, R39: 1K; R_0805_2012Metric_Pad1.20x1.40mm_HandSolder
R5, R12, R26, R33, R40: 1k; R_0805_2012Metric_Pad1.20x1.40mm_HandSolder
R6, R7, R13, R14, R27, R28, R34, R35, R41, R42: 5.1k; R_0805_2012Metric_Pad1.20x1.40mm_HandSolder
SW1, SW3, SW7, SW9, SW11: RESET_B; SMD BUTTON 5.1x5.1
SW2, SW4, SW8, SW10, SW12: BOOT0/U_BUTT; SMD BUTTON 5.1x5.1
U1, U5, U13, U17, U21: STM32G03xxxxx; TSSOP-20_4.4x6.5mm_P0.65mm
U2, U6, U14, U18, U22: AT24C32; SOP-8_3.9x4.9mm_P1.27mm
U3, U7, U15, U19, U23: H7233-1; SOT-23
U4, U8, U16, U20, U24: CH340N; SOP-8_3.9x4.9mm_P1.27mm
mouse-bite-2mm-slot, mouse-bite-2mm-slot#2, mouse-bite-2mm-slot#3, mouse-bite-2mm-slot#4, mouse-bite-2mm-slot#5, mouse-bite-2mm-slot#6, mouse-bite-2mm-slot#7, mouse-bite-2mm-slot#8, mouse-bite-2mm-slot#9, mouse-bite-2mm-slot#10, mouse-bite-2mm-slot#11, mouse-bite-2mm-slot#12, mouse-bite-2mm-slot#13: VAL**; mouse-bite-2mm-slot

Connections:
+3V3: C1.1, C2.1, C4.2, C6.1, C9.1, C10.1, C11.1, C12.1, C14.2, C16.1, C19.1, C20.1, C31.1, C32.1, C34.2, C36.1, C39.1, C40.1, C41.1, C42.1, C44.2, C46.1, C49.1, C50.1, C51.1, C52.1, C54.2, C56.1, C59.1, C60.1, D4.2 (A), D6.2 (A), D11.2 (A), D13.2 (A), D25.2 (A), D27.2 (A), D32.2 (A), D34.2 (A), D39.2 (A), D41.2 (A), J1.4, J5.4, J13.4, J17.4, J21.4, JP3.2 (B), JP6.2 (B), JP12.2 (B), JP15.2 (B), JP18.2 (B), SW2.1, SW4.1, SW8.1, SW10.1, SW12.1, U1.4 (VDD/VDDA), U2.8 (VCC), U3.2 (VOUT), U4.5 (VCC), U4.8 (V3), U5.4 (VDD/VDDA), U6.8 (VCC), U7.2 (VOUT), U8.5 (VCC), U8.8 (V3), U13.4 (VDD/VDDA), U14.8 (VCC), U15.2 (VOUT), U16.5 (VCC), U16.8 (V3), U17.4 (VDD/VDDA), U18.8 (VCC), U19.2 (VOUT), U20.5 (VCC), U20.8 (V3), U21.4 (VDD/VDDA), U22.8 (VCC), U23.2 (VOUT), U24.5 (VCC), U24.8 (V3)
/D+: J2.6 (DP1), J2.8 (DP2), J6.6 (DP1), J6.8 (DP2), J14.6 (DP1), J14.8 (DP2), J18.6 (DP1), J18.8 (DP2), J22.6 (DP1), J22.8 (DP2), U4.1 (UD+), U8.1 (UD+), U16.1 (UD+), U20.1 (UD+), U24.1 (UD+)
/D-: J2.5 (DN2), J2.7 (DN1), J6.5 (DN2), J6.7 (DN1), J14.5 (DN2), J14.7 (DN1), J18.5 (DN2), J18.7 (DN1), J22.5 (DN2), J22.7 (DN1), U4.2 (UD-), U8.2 (UD-), U16.2 (UD-), U20.2 (UD-), U24.2 (UD-)
/VUSB: F1.1, F2.1, F4.1, F5.1, F6.1, J2.2 (VBUS), J2.11 (VBUS), J6.2 (VBUS), J6.11 (VBUS), J14.2 (VBUS), J14.11 (VBUS), J18.2 (VBUS), J18.11 (VBUS), J22.2 (VBUS), J22.11 (VBUS)
GND: C1.2, C2.2, C3.2, C5.2, C6.2, C7.2, C8.2, C9.2, C10.2, C11.2, C12.2, C13.2, C15.2, C16.2, C17.2, C18.2, C19.2, C20.2, C31.2, C32.2, C33.2, C35.2, C36.2, C37.2, C38.2, C39.2, C40.2, C41.2, C42.2, C43.2, C45.2, C46.2, C47.2, C48.2, C49.2, C50.2, C51.2, C52.2, C53.2, C55.2, C56.2, C57.2, C58.2, C59.2, C60.2, J1.3, J2.1 (GND_1), J2.12 (GND_2), J2.13 (SHIELD), J3.2, J4.10, J5.3, J6.1 (GND_1), J6.12 (GND_2), J6.13 (SHIELD), J7.2, J8.10, J13.3, J14.1 (GND_1), J14.12 (GND_2), J14.13 (SHIELD), J15.2, J16.10, J17.3, J18.1 (GND_1), J18.12 (GND_2), J18.13 (SHIELD), J19.2, J20.10, J21.3, J22.1 (GND_1), J22.12 (GND_2), J22.13 (SHIELD), J23.2, J24.10, R1.2, R2.2, R3.2, R4.2, R5.1, R6.1, R7.2, R8.2, R9.2, R10.2, R11.2, R12.1, R13.1, R14.2, R22.2, R23.2, R24.2, R25.2, R26.1, R27.1, R28.2, R29.2, R30.2, R31.2, R32.2, R33.1, R34.1, R35.2, R36.2, R37.2, R38.2, R39.2, R40.1, R41.1, R42.2, SW1.1, SW3.1, SW7.1, SW9.1, SW11.1, U1.5 (VSS/VSSA), U2.1 (A0), U2.2 (A1), U2.3 (A2), U2.4 (GND), U3.1 (GND), U4.3 (GND), U5.5 (VSS/VSSA), U6.1 (A0), U6.2 (A1), U6.3 (A2), U6.4 (GND), U7.1 (GND), U8.3 (GND), U13.5 (VSS/VSSA), U14.1 (A0), U14.2 (A1), U14.3 (A2), U14.4 (GND), U15.1 (GND), U16.3 (GND), U17.5 (VSS/VSSA), U18.1 (A0), U18.2 (A1), U18.3 (A2), U18.4 (GND), U19.1 (GND), U20.3 (GND), U21.5 (VSS/VSSA), U22.1 (A0), U22.2 (A1), U22.3 (A2), U22.4 (GND), U23.1 (GND), U24.3 (GND)
NRST: C3.1, C13.1, C33.1, C43.1, C53.1, J3.3, J7.3, J15.3, J19.3, J23.3, SW1.2, SW3.2, SW7.2, SW9.2, SW11.2, U1.6 (NRST), U5.6 (NRST), U13.6 (NRST), U17.6 (NRST), U21.6 (NRST)
unnamed: D2.1 (K), D9.1 (K), D23.1 (K), D30.1 (K), D37.1 (K), R2.1, R9.1, R23.1, R30.1, R37.1
unnamed: D3.1 (K), D10.1 (K), D24.1 (K), D31.1 (K), D38.1 (K), R3.1, R10.1, R24.1, R31.1, R38.1
unnamed: D5.1 (K), D12.1 (K), D26.1 (K), D33.1 (K), D40.1 (K), R4.1, R11.1, R25.1, R32.1, R39.1
unnamed: D6.1 (K), D13.1 (K), D27.1 (K), D34.1 (K), D41.1 (K), R5.2, R12.2, R26.2, R33.2, R40.2
unnamed: D7.2 (A), D14.2 (A), D28.2 (A), D35.2 (A), D42.2 (A), F1.2, F2.2, F4.2, F5.2, F6.2
unnamed: J2.4 (CC1), J6.4 (CC1), J14.4 (CC1), J18.4 (CC1), J22.4 (CC1), R7.1, R14.1, R28.1, R35.1, R42.1
unnamed: J2.10 (CC2), J6.10 (CC2), J14.10 (CC2), J18.10 (CC2), J22.10 (CC2), R6.2, R13.2, R27.2, R34.2, R41.2
unnamed: JP1.1 (A), JP4.1 (A), JP10.1 (A), JP13.1 (A), JP16.1 (A), U2.5 (SDA), U6.5 (SDA), U14.5 (SDA), U18.5 (SDA), U22.5 (SDA)
unnamed: JP2.1 (A), JP5.1 (A), JP11.1 (A), JP14.1 (A), JP17.1 (A), U2.6 (SCL), U6.6 (SCL), U14.6 (SCL), U18.6 (SCL), U22.6 (SCL)
unnamed: JP3.1 (A), JP6.1 (A), JP12.1 (A), JP15.1 (A), JP18.1 (A), R1.1, R8.1, R22.1, R29.1, R36.1, U2.7 (WP), U6.7 (WP), U14.7 (WP), U18.7 (WP), U22.7 (WP)
PA0: J3.7, J7.7, J15.7, J19.7, J23.7, U1.7 (PA0), U5.7 (PA0), U13.7 (PA0), U17.7 (PA0), U21.7 (PA0)
PA1: J3.8, J7.8, J15.8, J19.8, J23.8, U1.8 (PA1), U5.8 (PA1), U13.8 (PA1), U17.8 (PA1), U21.8 (PA1)
PA2/TX2: D3.2 (A), D10.2 (A), D24.2 (A), D31.2 (A), D38.2 (A), J3.9, J7.9, J15.9, J19.9, J23.9, U1.9 (PA2), U4.6 (TXD), U5.9 (PA2), U8.6 (TXD), U13.9 (PA2), U16.6 (TXD), U17.9 (PA2), U20.6 (TXD), U21.9 (PA2), U24.6 (TXD)
PA3/RX2: D5.2 (A), D12.2 (A), D26.2 (A), D33.2 (A), D40.2 (A), J3.10, J7.10, J15.10, J19.10, J23.10, U1.10 (PA3), U4.7 (RXD), U5.10 (PA3), U8.7 (RXD), U13.10 (PA3), U16.7 (RXD), U17.10 (PA3), U20.7 (RXD), U21.10 (PA3), U24.7 (RXD)
PA4: J3.11, J7.11, J15.11, J19.11, J23.11, U1.11 (PA4), U5.11 (PA4), U13.11 (PA4), U17.11 (PA4), U21.11 (PA4)
PA5: J4.1, J8.1, J16.1, J20.1, J24.1, U1.12 (PA5), U5.12 (PA5), U13.12 (PA5), U17.12 (PA5), U21.12 (PA5)
PA6: J4.2, J8.2, J16.2, J20.2, J24.2, U1.13 (PA6), U5.13 (PA6), U13.13 (PA6), U17.13 (PA6), U21.13 (PA6)
PA7: J4.3, J8.3, J16.3, J20.3, J24.3, U1.14 (PA7), U5.14 (PA7), U13.14 (PA7), U17.14 (PA7), U21.14 (PA7)
PA11: J4.5, J8.5, J16.5, J20.5, J24.5, U1.16 (PA11), U5.16 (PA11), U13.16 (PA11), U17.16 (PA11), U21.16 (PA11)
PA12: J4.6, J8.6, J16.6, J20.6, J24.6, U1.17 (PA12), U5.17 (PA12), U13.17 (PA12), U17.17 (PA12), U21.17 (PA12)
PA13/SWDIO: J1.1, J4.7, J5.1, J8.7, J13.1, J16.7, J17.1, J20.7, J21.1, J24.7, U1.18 (PA13/SWDIO), U5.18 (PA13/SWDIO), U13.18 (PA13/SWDIO), U17.18 (PA13/SWDIO), U21.18 (PA13/SWDIO)
PA14/SWCLK/BOOT0: C4.1, C14.1, C34.1, C44.1, C54.1, J1.2, J4.8, J5.2, J8.8, J13.2, J16.8, J17.2, J20.8, J21.2, J24.8, SW2.2, SW4.2, SW8.2, SW10.2, SW12.2, U1.19 (PA14/SWCLK), U5.19 (PA14/SWCLK), U13.19 (PA14/SWCLK), U17.19 (PA14/SWCLK), U21.19 (PA14/SWCLK)
PB0: J4.4, J8.4, J16.4, J20.4, J24.4, U1.15 (PB0), U5.15 (PB0), U13.15 (PB0), U17.15 (PB0), U21.15 (PB0)
PB3: J4.9, J8.9, J16.9, J20.9, J24.9, U1.20 (PB3), U5.20 (PB3), U13.20 (PB3), U17.20 (PB3), U21.20 (PB3)
PB7: J3.4, J7.4, J15.4, J19.4, J23.4, JP2.2 (B), JP5.2 (B), JP11.2 (B), JP14.2 (B), JP17.2 (B), U1.1 (PB7), U5.1 (PB7), U13.1 (PB7), U17.1 (PB7), U21.1 (PB7)
PC14: J3.5, J7.5, J15.5, J19.5, J23.5, JP1.2 (B), JP4.2 (B), JP10.2 (B), JP13.2 (B), JP16.2 (B), U1.2 (PC14), U5.2 (PC14), U13.2 (PC14), U17.2 (PC14), U21.2 (PC14)
PC15: D2.2 (A), D9.2 (A), D23.2 (A), D30.2 (A), D37.2 (A), J3.6, J7.6, J15.6, J19.6, J23.6, U1.3 (PC15), U5.3 (PC15), U13.3 (PC15), U17.3 (PC15), U21.3 (PC15)
VBUS: C5.1, C7.1, C8.1, C15.1, C17.1, C18.1, C35.1, C37.1, C38.1, C45.1, C47.1, C48.1, C55.1, C57.1, C58.1, D1.1 (K), D7.1 (K), D8.1 (K), D14.1 (K), D22.1 (K), D28.1 (K), D29.1 (K), D35.1 (K), D36.1 (K), D42.1 (K), J4.12, J8.12, J16.12, J20.12, J24.12, U3.3 (VIN), U7.3 (VIN), U15.3 (VIN), U19.3 (VIN), U23.3 (VIN)
VCC: D1.2 (A), D8.2 (A), D22.2 (A), D29.2 (A), D36.2 (A), J4.11, J8.11, J16.11, J20.11, J24.11
VDD: D4.1 (K), D11.1 (K), D25.1 (K), D32.1 (K), D39.1 (K), J3.1, J7.1, J15.1, J19.1, J23.1

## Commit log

2023-09-17 added all the files
    [Floppy Board v3.0-B_Cu.gbr, Floppy Board v3.0-B_Mask.gbr, Floppy Board v3.0-B_Paste.gbr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]
2023-09-17 footprint and simbol FB3
2024-05-15 updated pinout
    [Floppy Board v3.1 (bom).csv, Floppy Board v3.1.kicad_pcb]
